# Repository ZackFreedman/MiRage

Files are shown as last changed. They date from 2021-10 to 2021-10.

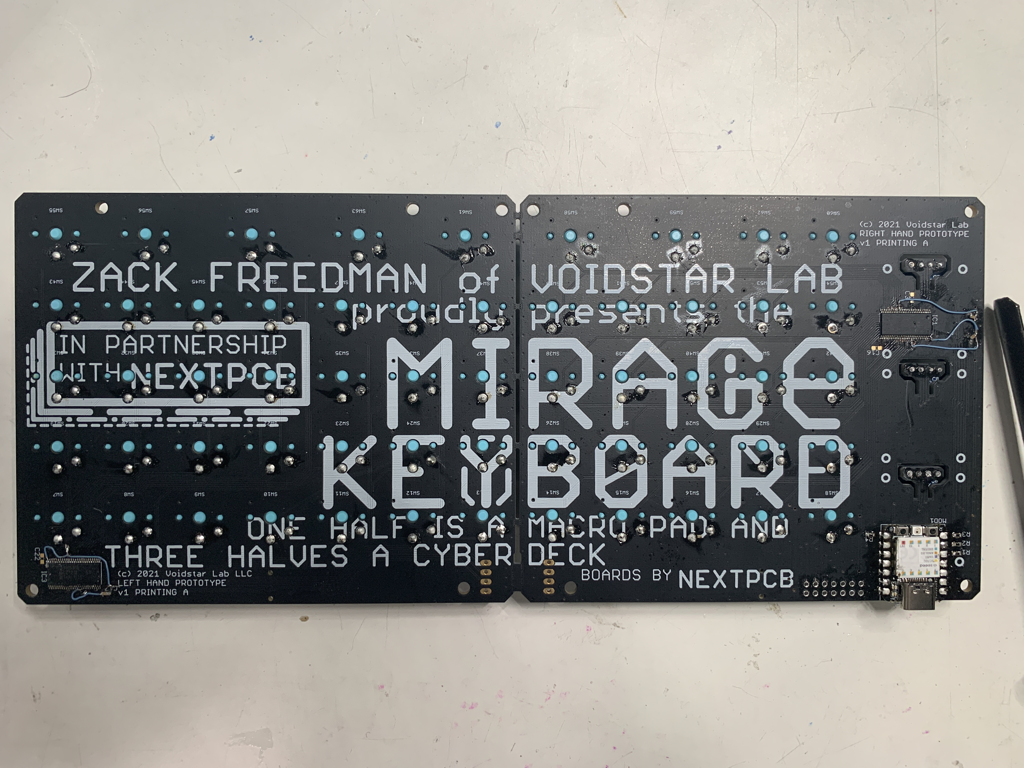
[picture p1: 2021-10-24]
IMG_4410.JPG

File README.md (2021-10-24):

# MiRage Modular Keyboard
## © 2021 Zack Freedman of Voidstar Lab
## Licensed Creative Commons 4.0 Attribution Noncommercial Share-Alike

The MiRage is a 60% ortholinear keyboard with three clickable OLED displays, intended for Kailh Choc switches and running custom CircuitPython firmware on a Seeedstudio Xiao RP2040. 

***THIS PROJECT IS INCOMPLETE. DO NOT MAKE IT.***

The PCB can be populated as-is for a "plank" keyboard or broken in half for a split board. The right half can be used independently as the Rage Pad numberpad/macro pad/stream deck.

This was designed for a YouTube video on my channel: https://youtu.be/Fg0V5M0llaE It will be improved and sold as a kit, and will form part of a larger project called the Fata Morgana cyberdeck.

Fusion 360 model: https://a360.co/3vEh6YI

The PCB, firmware, keymaps, and models have major issues that need to be fixed before moving forward. ***This project is not ready to be reproduced. Do not attempt to make it.*** Keymap instructions, assembly guide, BOM, and other documentation will be provided once the project is ready for release.

My component choices are final. Attempts to change my mind will be roasted in a future video.

Libraries are temporarily included for testing purposes. These will be replaced by references on release.

Keymaps are lists of bindings in the format:
R\[Row #\], K\[Key #\]: \[Key name (optional)\] # Comments start with a hash
	On press: \[Command(s) to perform once as soon as user presses key\]
	On click: \[Command(s) to perform when user presses and releases key within a few hundred milliseconds\]
	On double-click: \[Command(s) to perform when user presses and releases key twice within a few hundred milliseconds. The dash in 'double-click' is not optional.\]
	On hold: \[Command(s) to perform when user holds key for more than a few hundred ms. These generally repeat or remain in effect until the key is released.\]
	On release: \[Command(s) to perform once when user releases key. This is done after On Click and On Double-Click events are finished, and after ongoing On Hold events are cleaned up.\]

Actions you can bind to a key or event:
- `LEFT SHIFT`: Specify key bindings by naming them in all caps. You can see all the available key names in `keynames.py`. Key names must be in all caps. Spaces are optional. If a key is bound inline, it binds all events.
- `Click LEFT SHIFT`: This key will be pressed and instantly released a single time, even if this is called by an On Hold event. Clicking a key that's already Pressed will release, press, and release it.
- `Press LEFT SHIFT`: This key will be pressed indefinitely. Pressing a key that's already Pressed has no effect. Remember to add a way to release it...
- `Release LEFT SHIFT`: This key will be released. No effect if the key is not Pressed.
- `CTRL + ALT + DELETE`: Performs an operation on multiple keys simultaneously. You can Click, Press, Release, or straight-up bind key combos as if they were individual keys! Spaces around the plus signs are optional.
- `Switch to Numpad Layer`: Invokes specified layer indefinitely. This is case-insensitive. You don't need to include the layer's extension. Make sure to read the Layer Gotchas below!
- `Leave Numpad Layer`: If specified layer is currently invoked, dismisses it.
- `Switch to Numpad Layer until released`: Invokes the specified layer as long as this key remains held, and dismisses it when released. Cannot be bound to On Press, On Click, On Double-Click, or On Release events. **While in effect, layers above the one that defined this action do not apply to this key**.
- `Toggle Numpad Layer`: Acts as a Switch To action if specified layer is not currently in effect, and a Leave action if it is. Note that this can be blocked by layers above it, so make sure the new layer leaves this key open!
- `Go home`: Dismisses all invoked layers.
- `Type "Hello world!"`: Types the specified string a single time, one letter at a time. **Don't put double quotes and commas in the string!** Use `[DOUBLE QUOTES]` and `[COMMA]` instead! Any necessary keys that are currently Pressed will be released, pressed, and released again.
- `Type "Hello World!" repeatedly`: When bound to an On Press or On Hold event, types the string over and over. Extremely annoying.
- `wait 200ms`: Blocks everything for that much time. You can specify milliseconds, seconds, or minutes, in full or using ms, msec, sec, s, m, or min. Used in command sequences.
- `Click WIN+R, wait 200ms, type "cmd", click ENTER`: Sequence any combination of actions with commas. Each action is performed in its entirety before moving on. The On Hold behavior of a command sequence is not yet defined.
- `Nothing`: Allows keys on upper layers to block actions on lower layers without any side effects.
- `Pass through`: Sends this operation to the next lowest layer.
- `Reload keymaps`: Triggers a Go Home action, then reloads all the keymaps. 
- `Reset keyboard`: Triggers a software reset - disconnects from PC, reloads keymaps, and reconnects.
- `Bootloader`: Enters UF2 bootloader - disconnects from PC, kills CircuitPython, and reconnects as UF2 flash drive. **There is no way to return from the bootloader to the code without unplugging the keyboard.** This is an inbuilt limit of the bootloader and beyond my control.

Row and key numbers are zero-indexed, and refer to the physical placement of the keys on the keyboard. **These have nothing to do with the schematic. It's common sense numbering** Row 0, Key 0 is the top-left key.

Whitespace and line terminators are irrelevent. You can even use tabs, you sick bastard. UTF-8 encoding is strongly recommended; not sure how well Python handles bigger characters.

You can actually define the same key and same key action multiple times in the same map. This has the same effect as creating Sequences, and is extremely obnoxious to debug. I can't prevent you from doing it, but I can say "I told you so."

Layer Gotchas!
- Each layer's name is the same as the filename of the keymap that defined it, and is case- and extension-insensitive. **If multiple keymap files have the same name with different capitalization, the keyboard will crash on purpose just to spite you.**
- One layer must be called Base Layer. This is not optional. **The keyboard will not boot unless there's an applicable Base Layer.**
- The Base Layer is always in effect. When another layer is invoked, it's "stacked" on top. Invoking another layer stacks it on the other layer, and so on.
- When a key event happens, it's sent to the topmost layer. If that layer doesn't handle it, the next layer is checked, and so on. If you want the event to fall through anyways, such as in a sequence, use the `Pass through` action.
- Layer-related actions **DO NOT** apply immediately. Instead, the system reads every key, completes every Action fired, then applies any layer actions. This makes the layer switching process more predictable if multiple keys were pressed. 
- When a layer is invoked, if it's already in the stack, it's moved to the top.
- You cannot invoke or dismiss the Base Layer. Attempting to do so has no effect.
- The layer(s) selected by Layer Select Widgets have special slots above the Base Layer and just below the layer stack. If multiple clicky displays have Layer Select Widgets, the top screen layer is just below the layer stack and the bottom screen layer just above the Base Layer.
- If a layer selected by a Layer Select Widget is invoked, it moves from its special slot to the top of the stack. If it's dismissed, it returns to its special slot.
- Folders are provided for MiRage and Rage keymaps. Only the relevant ones apply.
- *Needs to be implemented:* When a layer is dismissed, if one or more keys with On Hold events defined by that layer are held, the On Hold ends. If one or more held keys have an On Release event, it's called. Pass Through actions in these events are ignored.

PCB problems to fix:
- VDD and VSS supply pins of PCA9505 I/O expanders are reversed
- RESET pins of PCA9505s must be pulled up
- Choc footprints will be extended to support Cherry MX switches
- Cut relief under microcontroller footprint for Adafruit QT PY. This part is **NOT** currently compatible.
- Increase size and number of breakaway tabs
- Right-angle headers are too far apart
- Add at least 4 keys
- Bottom screws are blocked by lowest row of keycaps
- Split is shifted one row to the left from usual typing position

Enclosure problems to fix: 
- Missing holes to access BOOT and RESET buttons
- Missing holes to view onboard LEDs
- Cutout for USB cable is too small 
- Rubber foot relief diameter too small and prone to sagging
- Bottom feet are too far from edges
- A small amount of PCB text is visible - poor fit and finish
- Magnetic applique falls off too easily
- Plank enclosure has header relief on wrong side
- Display buttons can crack if mashed down very hard

Code problems to fix (that I can remember off the top of my head, there are a lot)
- Rage board not implemented (not detected or automatically switched)
- Unplugging left side during runtime causes crash
- Code needs to be sped up about 200%
- Widget updating code needs to be sped up about 5000%
- Rage keymaps are missing layer switches
- Only key bindings can be defined inline
- Interactions between key event bindings and inline key bindings are unspecified
- Hold events lag, as if a click or double-click event were also bound
- Double-clicking also fires Click event
- Ongoing Hold events end sloppily if a layer switch overrides that binding
- No visual feedback for syntax errors, exceptions, layer switches, modal Lock keys, etc
- We need more widgets
- Fallback behavior in case of keymap errors
- Occasional failure to auto-run code on boot
- Including a comma in a 'Type' command crashes parser 
- If a key down command is sent then a Bootloader command runs, the key is never released
- Configuration setting is needed to redefine WINDOWS and ALT to GUI and OPTION 
- **Poor performance is due to CircuitPython, not I/O expanders. These I/O expanders can be polled over 1,000 times a second. This code would be MASSIVELY slower if a matrix were used instead of I/O expanders.**

Additional things to create:
- Plank enclosure without 3.5mm plug relief
- Split enclosure with header relief
- Rage (right hand) enclosure without 3.5mm plug relief
- Dashboard widget
- Widget that interacts with desktop
- Set typing speed 
- Enable/disable NKRO (hardcoded enabled for now due to nature of boot.py)
- Config file with widget assignments, click/hold timeout, base repeat rate, etc
- ZIF connectors to attach the MiRage to other Fata Morgana components via ribbon cables

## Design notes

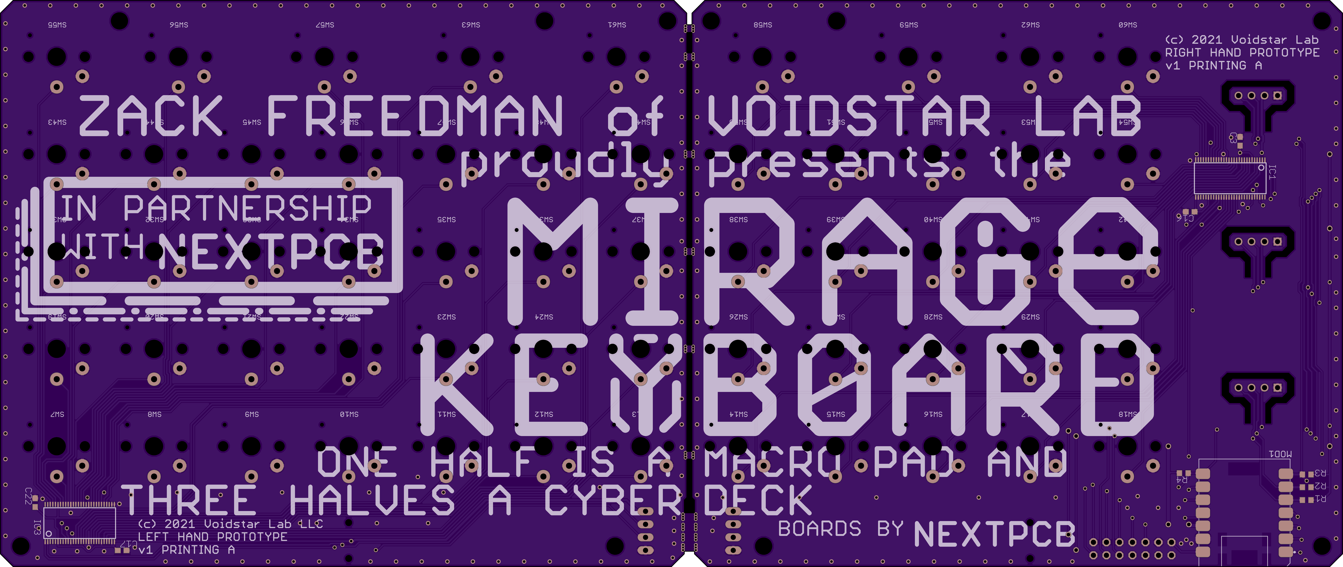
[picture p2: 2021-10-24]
021fd47c4467d378a9abb35864a4393c.png

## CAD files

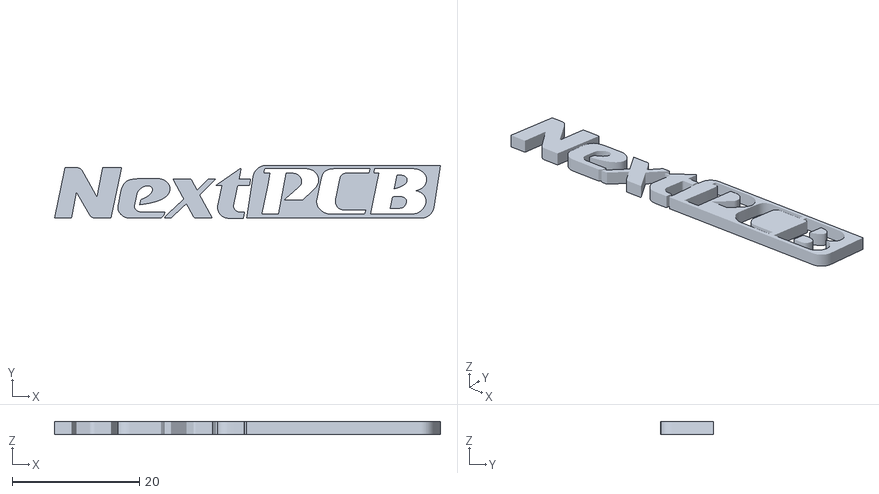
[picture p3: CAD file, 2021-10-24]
Models/Parts Used in Both Versions/NextPCB Inlay.stl
60.7 x 8.36 x 2.00

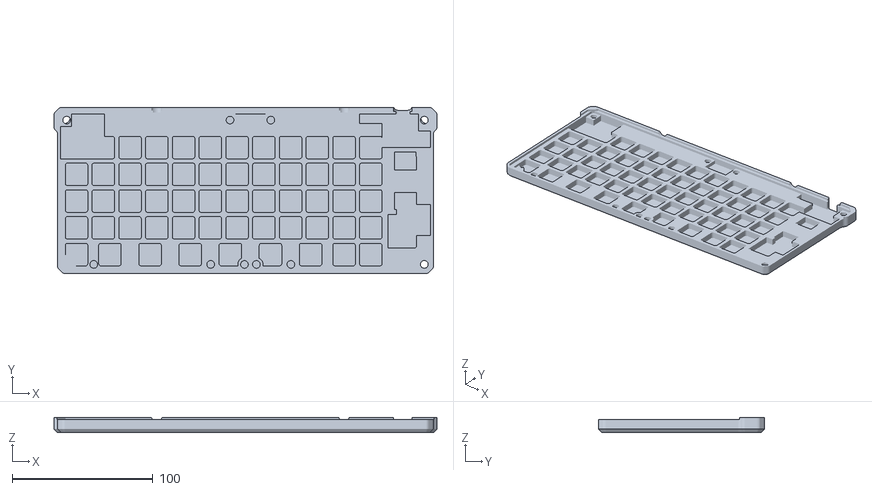
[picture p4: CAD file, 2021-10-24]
Models/Plank Version/For 300mm Printers/Monolithic Chassis.stl
272.0 x 118.0 x 10.5

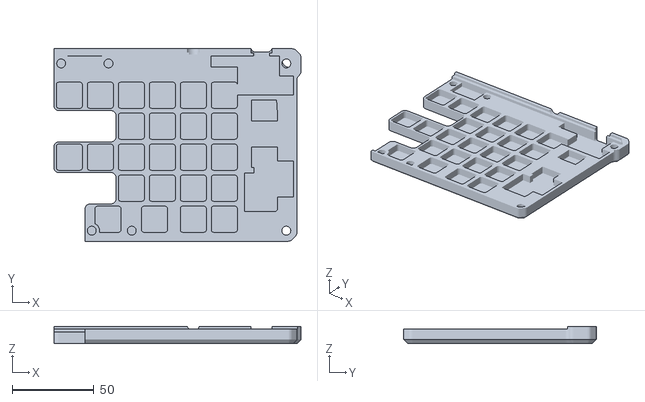
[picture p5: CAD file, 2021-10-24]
Models/Plank Version/For Normie Printers/Chassis Right.stl
151.4 x 118.0 x 10.5

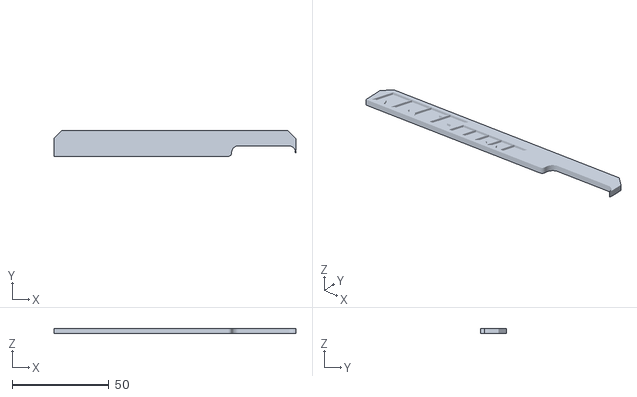
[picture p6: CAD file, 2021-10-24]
Models/Split Version/Right Nameplate for Rage.stl
124.9 x 13.3 x 2.60

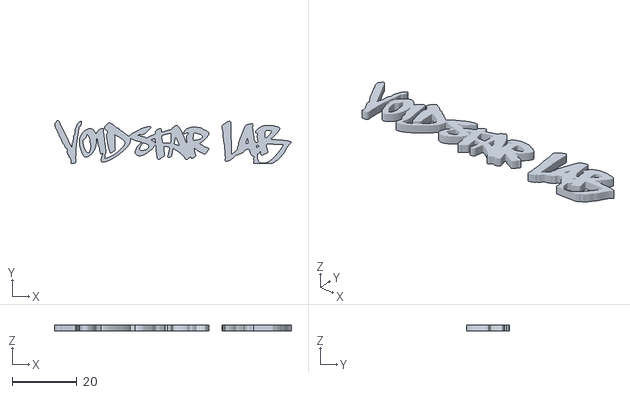
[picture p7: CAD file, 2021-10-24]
Models/Parts Used in Both Versions/Voidstar Lab Inlay.stl
73.4 x 13.3 x 2.00

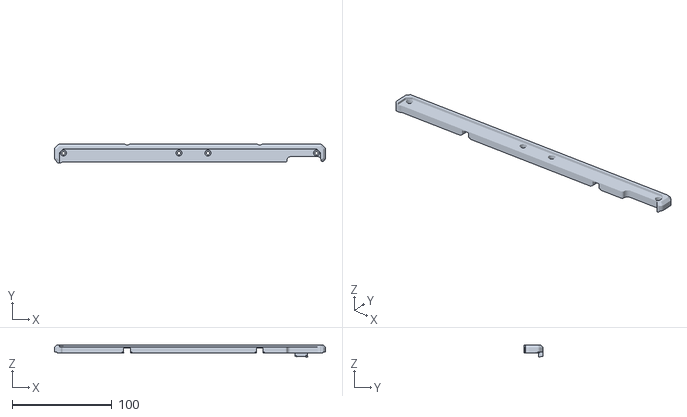
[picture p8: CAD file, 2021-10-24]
Models/Plank Version/For 300mm Printers/Monolithic Top Cover.stl
272.0 x 18.9 x 12.1

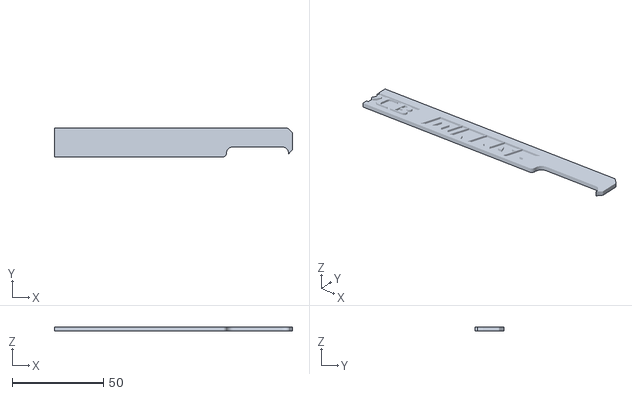
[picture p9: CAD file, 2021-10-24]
Models/Plank Version/For Normie Printers/Nameplate Right.stl
130.1 x 15.7 x 2.00

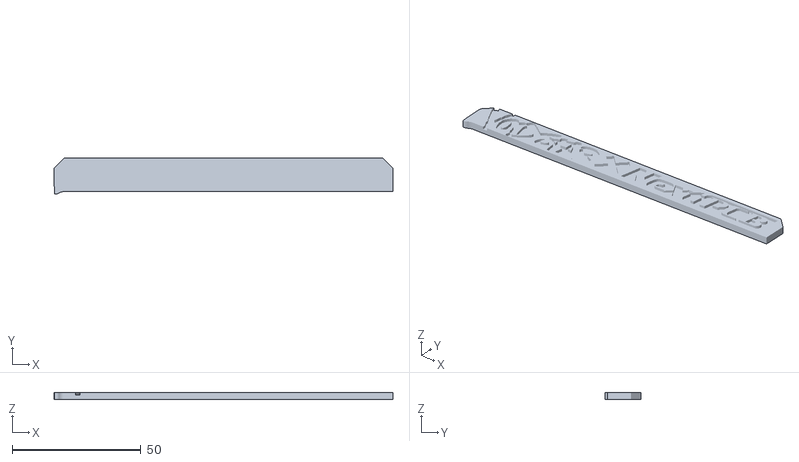
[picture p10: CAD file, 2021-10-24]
Models/Split Version/Left Nameplate.stl
131.4 x 13.9 x 2.60

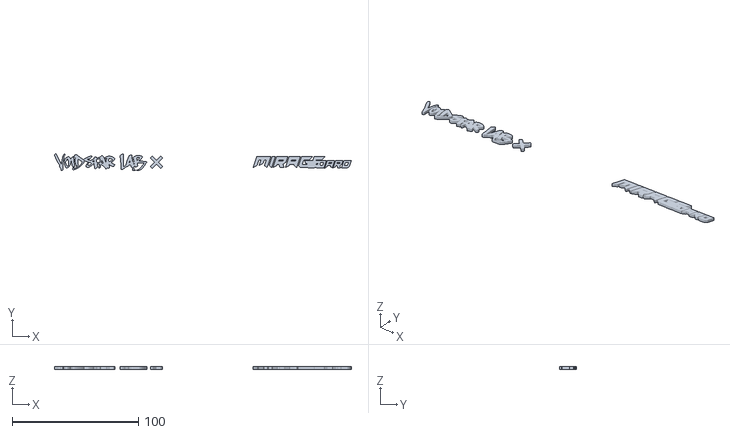
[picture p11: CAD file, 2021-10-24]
Models/Parts Used in Both Versions/Board Inlay.stl
235.5 x 13.3 x 2.00

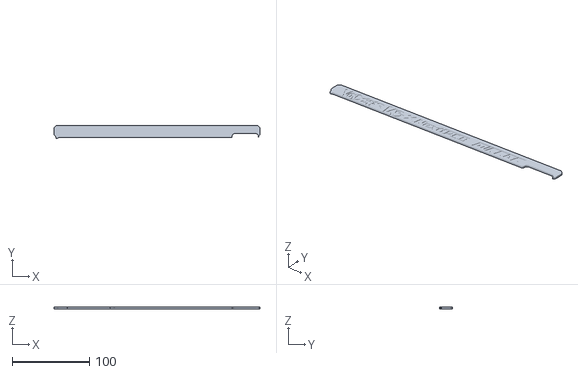
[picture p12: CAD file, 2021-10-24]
Models/Plank Version/For 300mm Printers/Monolithic Nameplate.stl
267.2 x 16.5 x 2.00

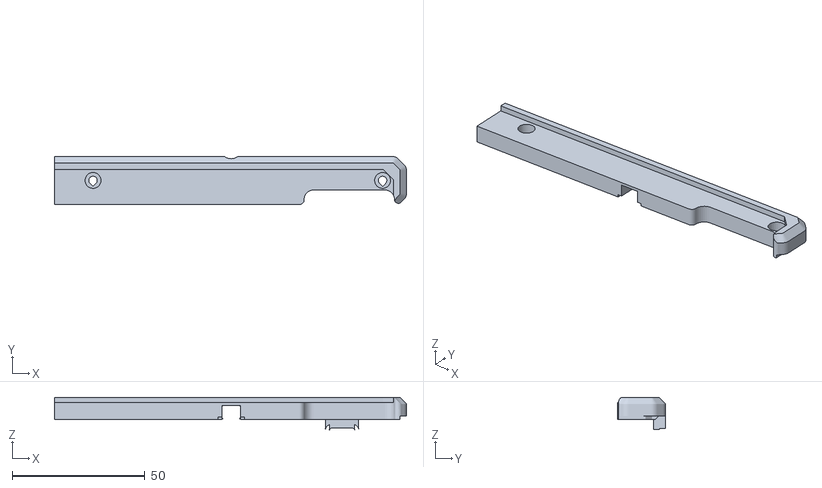
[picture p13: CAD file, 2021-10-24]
Models/Plank Version/For Normie Printers/Top Cover Right.stl
132.5 x 18.1 x 12.1

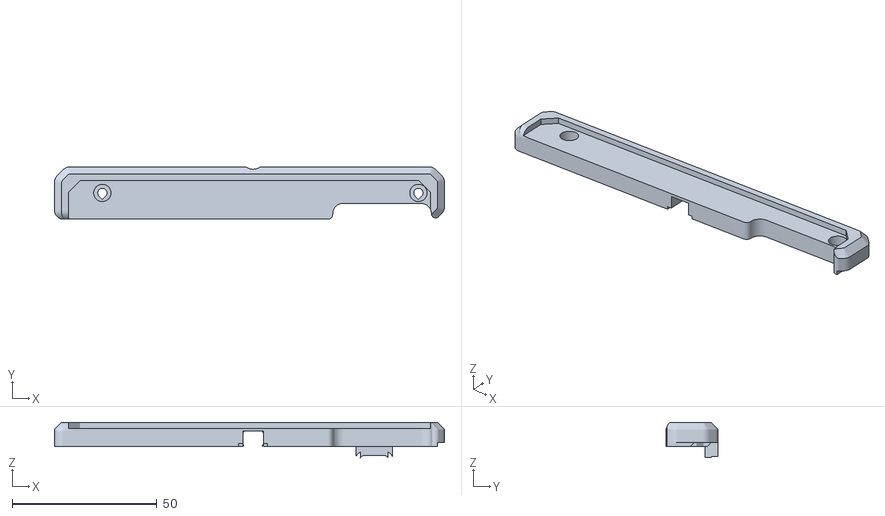
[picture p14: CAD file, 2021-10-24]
Models/Split Version/Right Top Cover.stl
134.5 x 18.1 x 12.1

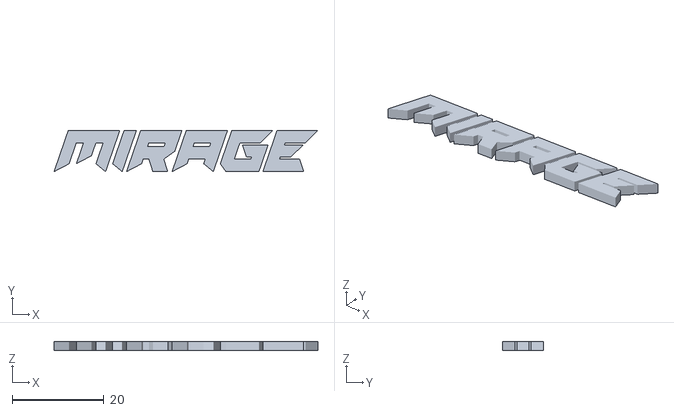
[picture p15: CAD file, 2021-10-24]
Models/Parts Used in Both Versions/Mirage Inlay.stl
57.4 x 9.00 x 2.00

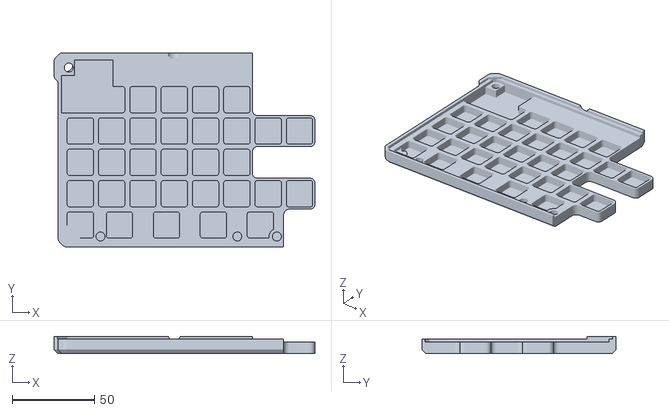
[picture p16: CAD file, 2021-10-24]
Models/Plank Version/For Normie Printers/Chassis Left.stl
158.4 x 118.0 x 10.5

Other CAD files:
Models/Split Version/Right Chassis.stl
Models/Parts Used in Both Versions/Cross Inlay.stl
Models/Plank Version/For Normie Printers/Nameplate Left.stl
Models/Split Version/Left Top Cover.stl
Models/Parts Used in Both Versions/OLED Clicky Display Frame.stl
Models/Plank Version/For Normie Printers/Top Cover Left.stl
Models/Split Version/Left Chassis.stl
Models/Split Version/Right Nameplate for MiRage.stl

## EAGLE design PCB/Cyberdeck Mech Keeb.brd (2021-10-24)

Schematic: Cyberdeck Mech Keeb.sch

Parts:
C3, C16, C17, C22: 0.1uF; C0603
CN1, CN2: AUDIO-JACK3; AUDIO-JACK-TRRS-SMD
IC1, IC3: PCA9505; TSSOP56-6
J1, J2, J3, J5: SOLDERJUMPERTRACE; SJ_2S-TRACE
JP1, JP2: PINHD-1X4/90; 1X04/90
JP3: PINHD-2X7; 2X07
MOD1: MOUDLE-SEEEDUINO-XIAO; MOUDLE14P-2.54-21X17.8MM
MOD2, MOD3, MOD4: DISPLAY-OLED-128X64-I2C
R1, R2, R3, R4: 4.7k; R0603
SW1, SW2, SW3, SW4, SW5, SW6: SPST_TACT-EVQQ2; EVQ-Q2
SW7, SW8, SW9, SW10, SW11, SW12, SW13, SW14, SW15, SW16, SW17, SW18, SW19, SW20, SW21, SW22, SW23, SW24, SW25, SW26, SW27, SW28, SW29, SW30, SW31, SW32, SW33, SW34, SW35, SW36, SW37, SW38, SW39, SW40, SW41, SW42, SW43, SW44, SW45, SW46, SW47, SW48, SW49, SW50, SW51, SW52, SW53, SW54, SW55, SW56, SW57, SW58, SW59, SW60, SW61, SW62, SW63: KEYSWITCH-PLAIN-CHOC-1U; CHOC-1U

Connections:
!INTERRUPT: IC1.55 (!INT)
!INTERRUPT': IC3.55 (!INT)
!RESET: IC1.56 (!RESET)
!RESET': IC3.56 (!RESET)
+3V3: C3.1, C16.1, CN1.TIP, IC1.6 (VSS), IC1.11 (VSS), IC1.23 (VSS), IC1.27 (A0), IC1.28 (A1), IC1.29 (A2), IC1.34 (VSS), IC1.39 (VSS), IC1.51 (VSS), J5.2, JP1.1, JP3.6, MOD1.12 (3V3), MOD2.2 (VCC), MOD3.2 (VCC), MOD4.2 (VCC), R1.2, R2.2, R3.2, R4.2
BAR: IC1.4 (IO0_1), SW29.CHOC1 (P0)
D0: JP3.1, MOD1.1 (PA02_A0_D0)
D1: JP3.3, MOD1.2 (PA4_A1_D1)
D2: JP3.5, MOD1.3 (PA10_A2_D2)
D3: JP3.7, MOD1.4 (PA11_A3_D3)
D8: JP3.12, MOD1.9 (PA7_A8_D8_SCK)
D9: JP3.10, MOD1.10 (PA5_A9_D9_MISO)
D10: JP3.8, MOD1.11 (PA6_A10_D10_MOSI)
GND: C3.2, C16.2, CN1.EARTH, IC1.18 (VDD), IC1.30 (!OE), IC1.46 (VDD), J1.2, JP1.4, JP3.4, MOD1.13 (GND), MOD2.1 (GND), MOD3.1 (GND), MOD4.1 (GND), SW1.A, SW2.A, SW3.A, SW4.A, SW5.A, SW6.A, SW14.CHOC2 (P1), SW15.CHOC2 (P1), SW16.CHOC2 (P1), SW17.CHOC2 (P1), SW18.CHOC2 (P1), SW26.CHOC2 (P1), SW27.CHOC2 (P1), SW28.CHOC2 (P1), SW29.CHOC2 (P1), SW30.CHOC2 (P1), SW38.CHOC2 (P1), SW39.CHOC2 (P1), SW40.CHOC2 (P1), SW41.CHOC2 (P1), SW42.CHOC2 (P1), SW50.CHOC2 (P1), SW51.CHOC2 (P1), SW52.CHOC2 (P1), SW53.CHOC2 (P1), SW54.CHOC2 (P1), SW58.CHOC2 (P1), SW59.CHOC2 (P1), SW60.CHOC2 (P1), SW62.CHOC2 (P1)
GND2: C17.2, C22.2, CN2.EARTH, IC3.18 (VDD), IC3.29 (A2), IC3.30 (!OE), IC3.46 (VDD), J1.1, JP2.1, SW7.CHOC2 (P1), SW8.CHOC2 (P1), SW9.CHOC2 (P1), SW10.CHOC2 (P1), SW11.CHOC2 (P1), SW12.CHOC2 (P1), SW13.CHOC2 (P1), SW19.CHOC2 (P1), SW20.CHOC2 (P1), SW21.CHOC2 (P1), SW22.CHOC2 (P1), SW23.CHOC2 (P1), SW24.CHOC2 (P1), SW25.CHOC2 (P1), SW31.CHOC2 (P1), SW32.CHOC2 (P1), SW33.CHOC2 (P1), SW34.CHOC2 (P1), SW35.CHOC2 (P1), SW36.CHOC2 (P1), SW37.CHOC2 (P1), SW43.CHOC2 (P1), SW44.CHOC2 (P1), SW45.CHOC2 (P1), SW46.CHOC2 (P1), SW47.CHOC2 (P1), SW48.CHOC2 (P1), SW49.CHOC2 (P1), SW55.CHOC2 (P1), SW56.CHOC2 (P1), SW57.CHOC2 (P1), SW61.CHOC2 (P1), SW63.CHOC2 (P1)
unnamed: IC1.53 (IO4_6), SW4.B (S)
unnamed: IC3.48 (IO4_2), SW7.CHOC1 (P0)
unnamed: IC1.45 (IO4_0), SW5.B (S)
unnamed: IC3.9 (IO0_5), SW8.CHOC1 (P0)
unnamed: IC1.52 (IO4_5), SW2.B (S)
unnamed: IC3.10 (IO0_6), SW9.CHOC1 (P0)
unnamed: IC1.7 (IO0_3), SW27.CHOC1 (P0)
unnamed: IC3.12 (IO0_7), SW10.CHOC1 (P0)
unnamed: IC3.25 (IO2_2), SW25.CHOC1 (P0)
unnamed: IC1.21 (IO1_7), SW58.CHOC1 (P0)
unnamed: IC1.42 (IO3_5), SW18.CHOC1 (P0)
unnamed: IC3.47 (IO4_1), SW32.CHOC1 (P0)
unnamed: IC3.22 (IO2_0), SW49.CHOC1 (P0)
unnamed: IC3.49 (IO4_3), SW44.CHOC1 (P0)
unnamed: IC1.8 (IO0_4), SW26.CHOC1 (P0)
unnamed: IC1.37 (IO3_1), SW14.CHOC1 (P0)
unnamed: IC1.3 (IO0_0), SW30.CHOC1 (P0)
unnamed: IC3.35 (IO2_7), SW57.CHOC1 (P0)
unnamed: IC3.20 (IO1_6), SW12.CHOC1 (P0)
unnamed: IC3.44 (IO3_7), SW56.CHOC1 (P0)
unnamed: IC1.15 (IO1_2), SW54.CHOC1 (P0)
unnamed: IC3.54 (IO4_7), SW55.CHOC1 (P0)
unnamed: IC1.9 (IO0_5), SW42.CHOC1 (P0)
unnamed: IC3.19 (IO1_5), SW24.CHOC1 (P0)
unnamed: IC3.50 (IO4_4), SW19.CHOC1 (P0)
unnamed: IC1.43 (IO3_6), SW1.B (S)
unnamed: IC3.45 (IO4_0), SW20.CHOC1 (P0)
unnamed: IC1.13 (IO1_0), SW39.CHOC1 (P0)
unnamed: IC3.41 (IO3_4), SW21.CHOC1 (P0)
unnamed: IC1.19 (IO1_5), SW62.CHOC1 (P0)
unnamed: IC3.36 (IO3_0), SW22.CHOC1 (P0)
unnamed: IC1.12 (IO0_7), SW40.CHOC1 (P0)
unnamed: IC3.26 (IO2_3), SW13.CHOC1 (P0)
unnamed: IC3.17 (IO1_4), SW36.CHOC1 (P0)
unnamed: IC3.13 (IO1_0), SW35.CHOC1 (P0)
unnamed: IC1.16 (IO1_3), SW60.CHOC1 (P0)
unnamed: IC3.16 (IO1_3), SW48.CHOC1 (P0)
unnamed: IC1.20 (IO1_6), SW59.CHOC1 (P0)
unnamed: IC1.14 (IO1_1), SW38.CHOC1 (P0)
unnamed: IC1.5 (IO0_2), SW28.CHOC1 (P0)
unnamed: IC3.14 (IO1_1), SW23.CHOC1 (P0)
unnamed: IC3.15 (IO1_2), SW11.CHOC1 (P0)
unnamed: IC1.54 (IO4_7), SW6.B' (S1)
unnamed: IC1.41 (IO3_4), SW17.CHOC1 (P0)
unnamed: IC1.22 (IO2_0), SW50.CHOC1 (P0)
unnamed: IC1.24 (IO2_1), SW51.CHOC1 (P0)
unnamed: IC3.52 (IO4_5), SW31.CHOC1 (P0)
unnamed: IC1.25 (IO2_2), SW52.CHOC1 (P0)
unnamed: IC1.44 (IO3_7), SW3.B (S)
unnamed: IC1.26 (IO2_3), SW53.CHOC1 (P0)
unnamed: IC3.42 (IO3_5), SW33.CHOC1 (P0)
unnamed: IC1.40 (IO3_3), SW16.CHOC1 (P0)
unnamed: IC3.37 (IO3_1), SW34.CHOC1 (P0)
unnamed: IC3.33 (IO2_6), SW63.CHOC1 (P0)
unnamed: IC1.38 (IO3_2), SW15.CHOC1 (P0)
unnamed: IC1.10 (IO0_6), SW41.CHOC1 (P0)
unnamed: IC3.53 (IO4_6), SW43.CHOC1 (P0)
unnamed: IC3.24 (IO2_1), SW37.CHOC1 (P0)
unnamed: IC3.43 (IO3_6), SW45.CHOC1 (P0)
unnamed: IC3.38 (IO3_2), SW46.CHOC1 (P0)
unnamed: IC3.32 (IO2_5), SW47.CHOC1 (P0)
unnamed: IC3.21 (IO1_7), SW61.CHOC1 (P0)
SCL: CN1.RING1, IC1.2 (SCL), J3.2, JP1.2, JP3.11, MOD1.6 (PA9_A5_D5_SCL), MOD2.3 (SCL), MOD3.3 (SCL), R2.1
SCL2: JP3.13, MOD1.8 (PB09_A7_D7_RX), MOD4.3 (SCL), R4.1
SCL': CN2.RING1, IC3.2 (SCL), J3.1, JP2.3
SDA: CN1.RING2, IC1.1 (SDA), J2.2, JP1.3, JP3.9, MOD1.5 (PA8_A4_D4_SDA), MOD2.4 (SDA), MOD3.4 (SDA), R1.1
SDA2: JP3.14, MOD1.7 (PB08_A6_D6_TX), MOD4.4 (SDA), R3.1
SDA': CN2.RING2, IC3.1 (SDA), J2.1, JP2.2
VCC/2: C17.1, C22.1, CN2.TIP, IC3.6 (VSS), IC3.11 (VSS), IC3.23 (VSS), IC3.27 (A0), IC3.28 (A1), IC3.34 (VSS), IC3.39 (VSS), IC3.51 (VSS), J5.1, JP2.4
VIN: JP3.2, MOD1.14 (5V)

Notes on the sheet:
Seeeduino XIAO (RP2040 if possible)

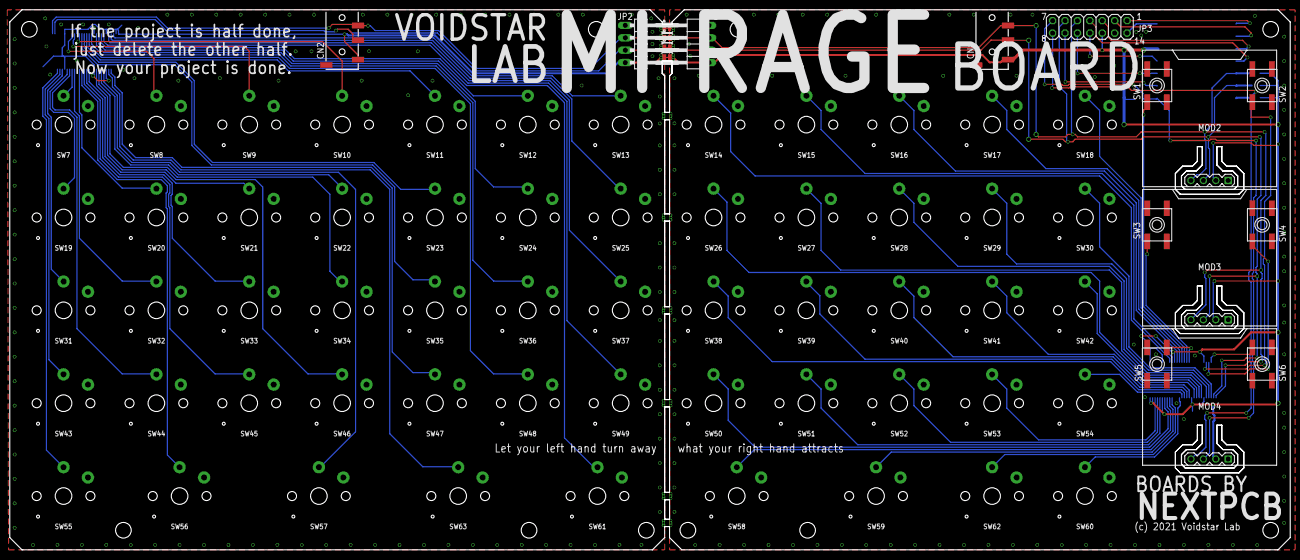
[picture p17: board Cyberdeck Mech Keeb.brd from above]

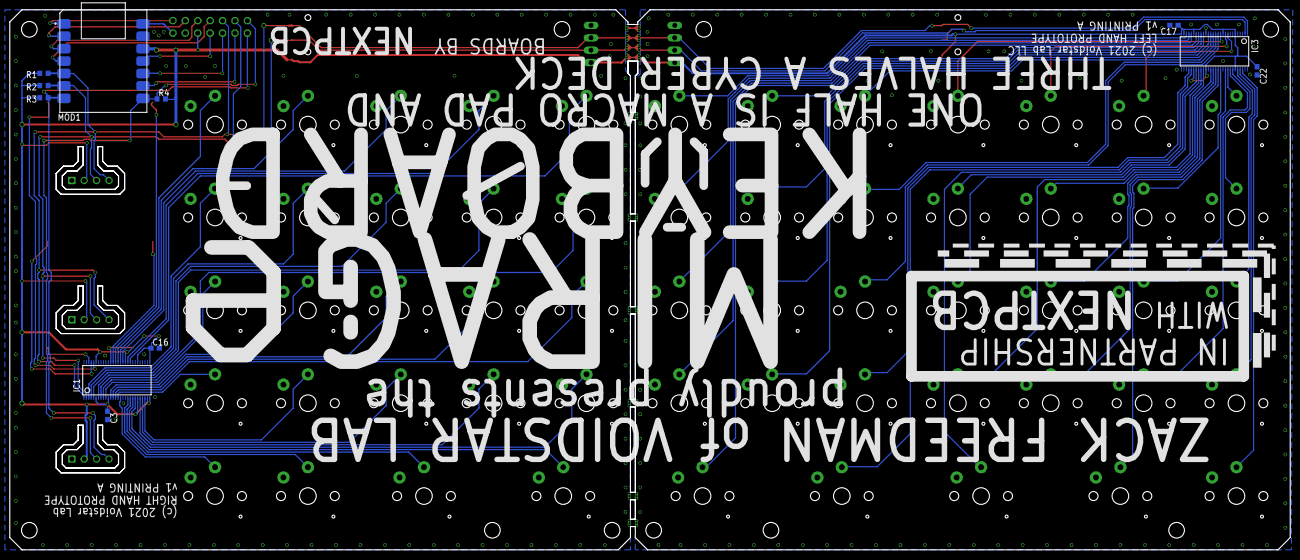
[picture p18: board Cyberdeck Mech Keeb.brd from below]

Board: 2 copper layers, 262.0 x 110.5 mm, 86 parts (11 on the bottom side), 81 nets.

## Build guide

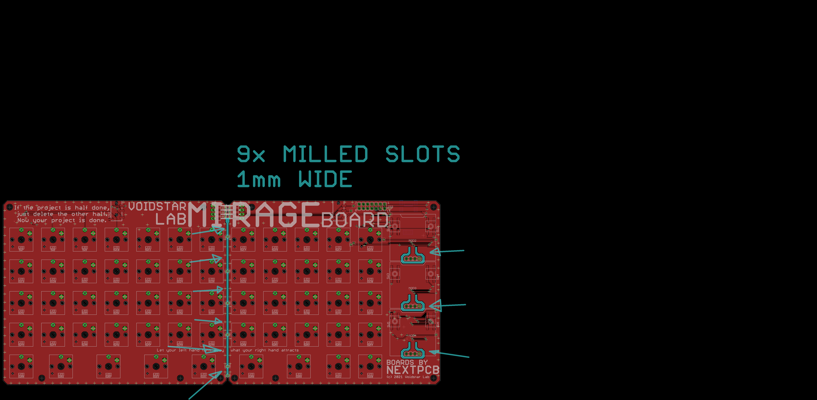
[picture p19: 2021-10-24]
PCB/v1 Gerbers/Milling Instructions.png

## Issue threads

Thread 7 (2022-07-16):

the PCB design isn't ergonomic by default

osimmac, 2022-07-16:
hey, if you're forcing people to use ortholinear and 5 rows high bc its more ergonomic, why not go all the way? the point of making it not split by default is space savings, but there NO reason to not put the clicky LED displays in the middle, separating the two halves. You'd just have to move it to the left side of the ride half. We're not silly monkey's who don't know how to touch type and can't properly keep our fingers where they should be. this would also allow both hands easy access to the OLED display. I propose 2 versions, one with displays in middle and one with them on the right side. Or you could make the displays a separate module, and allow them to go in between, or left or right side... :thinking:

ionstorm66, 2022-07-20:
Zach stated in the update video that the display will be kicked off into its own module, and the two haves will change to a singular ortholinear module.

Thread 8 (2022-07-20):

Add the option for magnetic connectors.

ionstorm66, 2022-07-20:
Would be nice to have the option to install magnetic connectors like these https://www.adafruit.com/product/5360 on the sides of the boards. That way you can have the modules linked together with only the single cable connected to the PC.

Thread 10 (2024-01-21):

Mk III code - where?

EliaTarasoff, 2024-01-21:
Sorry if I missed something obvious, but where's the source for the mark three? All I can see is one branch for mark two... :thinking:

SirBramble, 2024-01-23:
Been wondering the same for a while. But I assume its not ready, because its a complete rewrite in C++.

Would have been nice to have the current version though.

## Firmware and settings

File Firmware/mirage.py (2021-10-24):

import time
from pca950x import PCA950x
from util import timed_function

physical_key_assignments = {
    (0, 0, 5): (0, 1),  #  (which PCA9505, which bank, which line): (row, col)
    (0, 0, 6): (0, 2),
    (0, 0, 7): (0, 3),
    (0, 1, 0): (2, 4),
    (0, 1, 1): (1, 4),
    (0, 1, 2): (0, 4),
    (0, 1, 3): (3, 5),
    (0, 1, 4): (2, 5),
    (0, 1, 5): (1, 5),
    (0, 1, 6): (0, 5),
    (0, 1, 7): (4, 4),
    (0, 2, 0): (3, 6),
    (0, 2, 1): (2, 6),
    (0, 2, 2): (1, 6),
    (0, 2, 3): (0, 6),
    (0, 2, 5): (3, 4),
    (0, 2, 6): (4, 3),
    (0, 2, 7): (4, 2),
    (0, 3, 0): (1, 3),
    (0, 3, 1): (2, 3),
    (0, 3, 2): (3, 3),
    (0, 3, 4): (1, 2),
    (0, 3, 5): (2, 2),
    (0, 3, 6): (3, 2),
    (0, 3, 7): (4, 1),
    (0, 4, 0): (1, 1),
    (0, 4, 1): (2, 1),
    (0, 4, 2): (0, 0),
    (0, 4, 3): (3, 1),
    (0, 4, 4): (1, 0),
    (0, 4, 5): (2, 0),
    (0, 4, 6): (3, 0),
    (0, 4, 7): (4, 0),
    (1, 0, 0): (1, 11),
    (1, 0, 1): (1, 10),
    (1, 0, 2): (1, 9),
    (1, 0, 3): (1, 8),
    (1, 0, 4): (1, 7),
    (1, 0, 5): (2, 11),
    (1, 0, 6): (2, 10),
    (1, 0, 7): (2, 9),
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
}

screen_button_assignments = {
    (1, 3, 6): (0, 0),  # Top screen, left button
    (1, 3, 7): (1, 0),
    (1, 4, 0): (2, 0),
    (1, 4, 5): (0, 1),
    (1, 4, 6): (1, 1),
    (1, 4, 7): (2, 1)
}


class IOAssociation:
    __slots__ = 'input_line', 'row', 'col', 'is_a_key'

    def __init__(self, input_line, row, col, is_a_key):
        self.input_line = input_line
        self.row = row
        self.col = col
        self.is_a_key = is_a_key


class KeyGrid:
    def __init__(self, i2c, keymap, clicky_displays, keys=physical_key_assignments, buttons=screen_button_assignments):
        self.io_expanders = []
        self.key_associations = []

        self.i2c = i2c  # Should already be locked
        self.keymap = keymap
        self.clicky_displays = clicky_displays
        self.keys = keys
        self.buttons = buttons

        self.key_down_timestamps = {}
        self.keys_held = []
        self.recent_key_clicks = {}

        self.click_timeout = 0.1  # Release the key within this many seconds to fire a click
        self.double_click_timeout = 0.2  # Click again within this many seconds to fire a double click

    def setup(self):
        self.io_expanders.append(PCA950x(self.i2c, 0x23))
        self.io_expanders.append(PCA950x(self.i2c, 0x20))

        for io_expander in self.io_expanders:
            io_expander.reset()

        for index, io_expander in enumerate(self.io_expanders):
            for input_line in io_expander.input_lines:
                coords = index, input_line.bank, input_line.line

                if coords in self.keys:
                    row, col = self.keys[coords]
                    is_a_key = True
                elif coords in self.buttons:
                    row, col = self.buttons[coords]
                    is_a_key = False
                else:
                    continue

                self.key_associations.append(IOAssociation(input_line, row, col, is_a_key))

    # @timed_function
    def update(self):
        for index, io_expander in enumerate(self.io_expanders):
            io_expander.update()

        for line in self.key_associations:
            if line.input_line.fell:  # Key pressed down
                if line.is_a_key:
                    # print('Row {}, col {} pressed'.format(line.row, line.col))
                    self.keymap.fire_operation(line.row, line.col, 'press')
                    if self.clicky_displays is not None:
                        for display in self.clicky_displays:
                            display.on_keystroke(0x00)  # TODO: Only do something if a key was pressed, and pass in which key

                elif self.clicky_displays is not None:  # Is a clicky screen button
                    # print('Display {} {}-clicked'.format(line.row, 'right' if line.col else 'left'))
                    self.clicky_displays[line.row].on_click(line.col)

                self.key_down_timestamps[line] = time.monotonic()

            elif line.input_line.rose:
                if line in self.key_down_timestamps:
                    hold_length = time.monotonic() - self.key_down_timestamps[line]
                    # print('Held for', hold_length)
                else:
                    hold_length = 666
                    # print('WEIRD SHIT - Key rose without previously falling')

                del self.key_down_timestamps[line]

                if line.is_a_key:
                    # print('Row {}, col {} went high after {}ms'.format(line.row, line.col, hold_length))
                    
                    if hold_length <= self.click_timeout:
                        is_double_click = False

                        # print("That's a click")
                        
                        if line in self.recent_key_clicks:
                            if time.monotonic() - self.recent_key_clicks[line]\
                                <= self.double_click_timeout:
                                del self.recent_key_clicks[line]
                                is_double_click = True
                        else:
                            self.recent_key_clicks[line] = time.monotonic()

                        # TODO: When both a click and double click are assigned, clicking once should delay til DC threshold passed

                        if is_double_click:
                            # print("Row {}, col {} double-clicked".format(line.row, line.col))
                            self.keymap.fire_operation(line.row, line.col, 'double-click')
                        else:
                            # print('Row {}, col {} clicked'.format(line.row, line.col))
                            self.keymap.fire_operation(line.row, line.col, 'click')

                    if line in self.keys_held:
                        # print('Row {}, col {} no longer held'.format(line.row, line.col))
                        self.keymap.fire_operation(line.row, line.col, 'end hold')
                        self.keys_held.remove(line)

                    # print('Row {}, col {} released'.format(line.row, line.col))
                    self.keymap.fire_operation(line.row, line.col, 'release')

                else:
                    # On clicky display release event? 9
                    pass

            elif not line.input_line.value:
                if line in self.key_down_timestamps\
                    and time.monotonic() - self.key_down_timestamps[line] > self.click_timeout:
                    if line in self.keys_held:
                        self.keymap.fire_operation(line.row, line.col, 'continue hold')
                    else:
                        # print('Row {}, col {} now held'.format(line.row, line.col))
                        self.keys_held.append(line)
                        self.keymap.fire_operation(line.row, line.col, 'start hold')
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

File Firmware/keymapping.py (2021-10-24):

import os
from actions import *
import parser
from util import timed_function

action_pool = []  # Reuse actions to save memory


class KeyBinding:
    __slots__ = 'on_press_actions', 'on_click_actions', 'on_hold_actions',\
        'on_double_click_actions', 'on_release_actions', 'standard_behavior_actions'

    def __init__(self):
        self.on_press_actions = []
        self.on_click_actions = []
        self.on_hold_actions = []
        self.on_double_click_actions = []
        self.on_release_actions = []
        self.standard_behavior_actions = []

    def bind_action(self, operation, action):
        # print('Binding {} to {}'.format(action, operation))

        if operation == 'on press':
            self.on_press_actions.append(action)
        elif operation == 'on click':
            self.on_click_actions.append(action)
        elif operation == 'on hold':
            self.on_hold_actions.append(action)
        elif operation == 'on double-click':
            self.on_double_click_actions.append(action)
        elif operation == 'on release':
            self.on_release_actions.append(action)
        elif operation == 'standard' or operation is None:
            self.standard_behavior_actions.append(action)
        else:
            raise AttributeError('{} is not an operation'.format(operation))

    def reset(self):
        # print('Resetting binding')
        del self.on_press_actions[:]
        del self.on_click_actions[:]
        del self.on_hold_actions[:]
        del self.on_double_click_actions[:]
        del self.on_release_actions[:]
        del self.standard_behavior_actions[:]

    @staticmethod
    # @timed_function
    def _fire_actions(actions, how='one shot'):
        #should_fall_through = True
        fall_through_override = False

        for action in actions:
            if isinstance(action, PassThroughAction):
                fall_through_override = True 
                # print('Firing PassThroughAction')
                continue
            #should_fall_through = False
            if how is 'one shot':
                action.one_shot()
            elif how is 'start':
                action.start_hold()
            elif how is 'continue':
                action.continue_hold()
            elif how is 'end':
                action.end_hold()

        #return should_fall_through or fall_through_override
        return fall_through_override

    def press(self):
        if len(self.on_press_actions):
            return KeyBinding._fire_actions(self.on_press_actions)
        else:
            return KeyBinding._fire_actions(self.standard_behavior_actions, how='start')

    def click(self):
        return KeyBinding._fire_actions(self.on_click_actions)

    def start_hold(self):
        return KeyBinding._fire_actions(self.on_hold_actions, how='start')

    def continue_hold(self):
        return KeyBinding._fire_actions(self.on_hold_actions, how='continue')

    def end_hold(self):
        return KeyBinding._fire_actions(self.on_hold_actions, how='end')

    def double_click(self):
        return KeyBinding._fire_actions(self.on_double_click_actions)

    def release(self):
        if len(self.on_release_actions):
            return KeyBinding._fire_actions(self.on_release_actions)
        else:
            return KeyBinding._fire_actions(self.standard_behavior_actions, how='end')

    def needs_timing(self):
        return len(self.on_click_actions) \
            + len(self.on_hold_actions) \
            + len(self.on_double_click_actions) > 0

    def does_anything(self):
        return len(self.on_press_actions) \
            + len(self.on_click_actions) \
            + len(self.on_hold_actions) \
            + len(self.on_double_click_actions) \
            + len(self.on_release_actions) \
            + len(self.standard_behavior_actions) > 0


class Layer:
    def __init__(self, owner):
        self.owner = owner

        self.key_bindings = {}
        self.name = None
        self.unassigned_keys_fall_through = True

    def bind(self, row, col, action, operation=None):
        global action_pool
        action_to_bind = None

        # print('Binding {} to R{}, K{} {} op'.format(
            #str(action), row, col, operation if operation is not None else 'standard behavior'))

        for existing_action in action_pool:
            if action == existing_action:
                action_to_bind = existing_action
                # print('Reusing existing action')
                break

        if action_to_bind is None:
            # print('Creating new action')
            action_to_bind = action
            action_pool.append(action)

        if (row, col) in self.key_bindings:
            # print('Reusing existing binding')
            binding = self.key_bindings[row, col]
        else:
            # print('Creating new binding')
            binding = KeyBinding()
            self.key_bindings[row, col] = binding

        action_to_bind.associate_with(self.owner)

        binding.bind_action(operation, action_to_bind)

    def reset(self):
        self.key_bindings.clear()
        self.name = None
        self.unassigned_keys_fall_through = True

    def fire_operation(self, row, col, operation):
        # print('Firing a {} on R{}, K{} of layer {}'.format(operation, row, col, self.name))

        try:
            if operation == 'press':
                return self.key_bindings[row, col].press()
            elif operation == 'click':
                return self.key_bindings[row, col].click()
            elif operation == 'start hold':
                return self.key_bindings[row, col].start_hold()
            elif operation == 'continue hold':
                return self.key_bindings[row, col].continue_hold()
            elif operation == 'end hold':
                return self.key_bindings[row, col].end_hold()
            elif operation == 'double-click':
                return self.key_bindings[row, col].double_click()
            elif operation == 'release':
                return self.key_bindings[row, col].release()
            else:
                raise AttributeError('{} is not an operation'.format(operation))
        except KeyError:
            if not (row, col) in self.key_bindings:
                pass
                # print('This key has no bindings')
            elif not self.key_bindings[row, col].does_anything():
                pass
                # print('This key has no actions')

        return self.unassigned_keys_fall_through
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

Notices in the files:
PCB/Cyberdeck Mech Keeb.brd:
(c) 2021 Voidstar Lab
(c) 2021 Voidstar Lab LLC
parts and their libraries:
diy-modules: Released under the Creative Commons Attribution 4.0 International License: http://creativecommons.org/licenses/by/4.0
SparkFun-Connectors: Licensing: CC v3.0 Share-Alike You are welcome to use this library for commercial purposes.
